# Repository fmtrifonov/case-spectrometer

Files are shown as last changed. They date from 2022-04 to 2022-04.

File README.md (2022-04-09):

# case-spectrometer
Корпус для монтирования сцинтилляционного гама-спектрометра основанного на ФЭУ-85 в короб. Обеспечивает плотный прижим кристалла к фотоэлектронному умножителю.

В данном репозитории находятся:
- описание 
- 3D модели для сцинтилляционного гама-спектрометра в форматах
  - программы Fusion360 ```.f3z```
  - универсальном формате САПР ```.step```
  - полигональном формате ```.stl``` для 3d печати.
- инструкция по сборке.

## описание

Сборка по сути представляет из себя фитинг, где в одной его части закреплен ФЭУ, а в другой кристалл сцинтиллятора. Обе эти части могут продольно перемещаться вдоль оси, но зафиксированы от вращения с помощью стоек, монтируемых в короб. Гайка при вращение перемещается по резьбе вокруг фэу и поджимает колпак с кристаллом, обеспечивая плотный контакт ФЭУ и сцинтиллятора.

## инструкция по сборке

Для печати нужно загрузить модели в формате ```.stl```. В директории ```\Images``` можно посмотреть оптимальную ориентацию моделей при использовании FDM печати.
В детали ```symetric side``` после печати нужно досверлить отверстия сверлом 3mm.

### порядок сборки
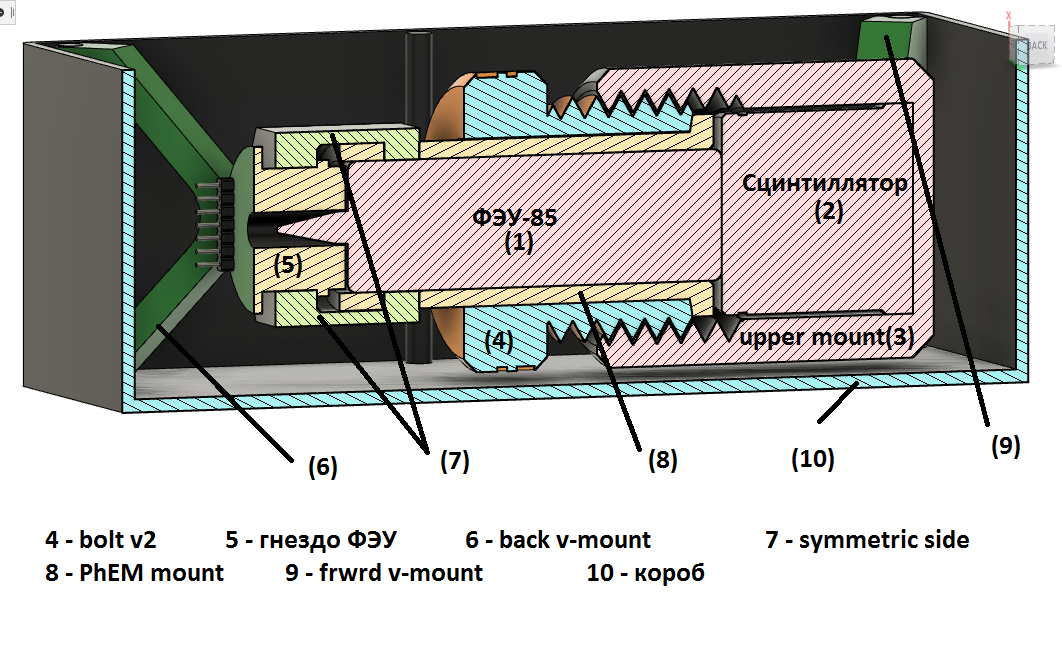
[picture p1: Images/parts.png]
Alt-текст Сборка в разрезе


На ФЭУ(1) установить деталь(8) и (4) как на рисунке.
Затем надевается гнездо питания(5) и деталь (8) фиксируется боковинками (7) снизу и сверху. 
В стакан (3) вставляется сцинтиллятор прозрачной стороной наружу. На него наносится оптическая смазка.
Стакан (3) навинчивается на болт (4) с запасом по ходу ~пол оборота. Прим. Запас хода оценивается расстоянием, которое пройдет кристалл до касания с ФЭУ, а не виднеющейся частью наружной резьбы.
К стакану прикручиваются ножки (9), а боковинки закрепляются ножками (6). Ножки (6) и (9) выравниваются в горизонталь (так, чтобы сборку можно было вставить в короб(10)), после чего гайка (4) закручевается до упора. 
ВНИМАНИЕ!!! Не переусердствуйте с затяжкой. В лучшем случае повредите печатные детали, в худшем - лопнет ФЭУ.

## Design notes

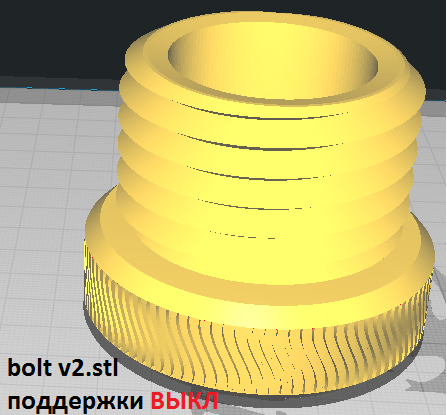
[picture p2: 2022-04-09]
Images/bolt v2.png

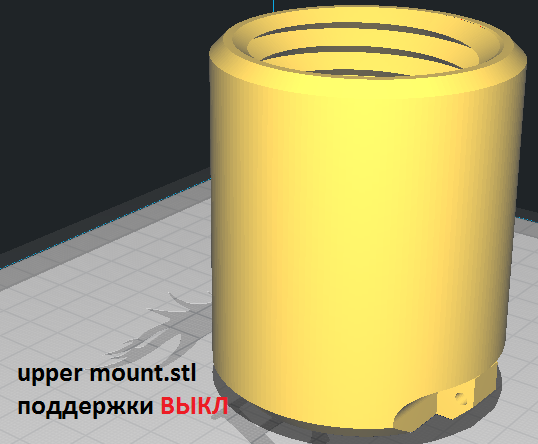
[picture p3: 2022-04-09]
Images/upper mount.png

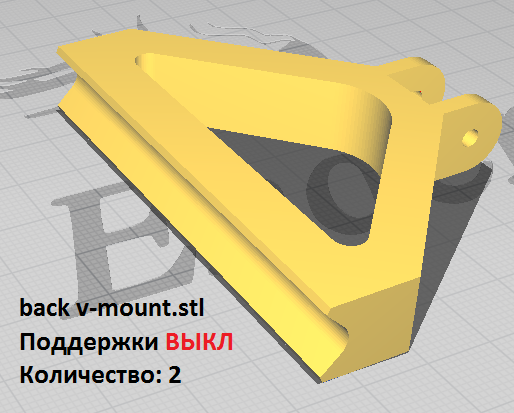
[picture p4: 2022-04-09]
Images/back v-mount.png

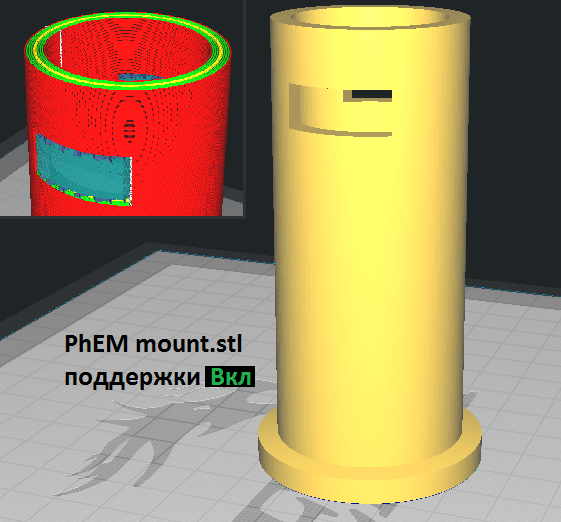
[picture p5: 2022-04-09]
Images/PhEM mount.png

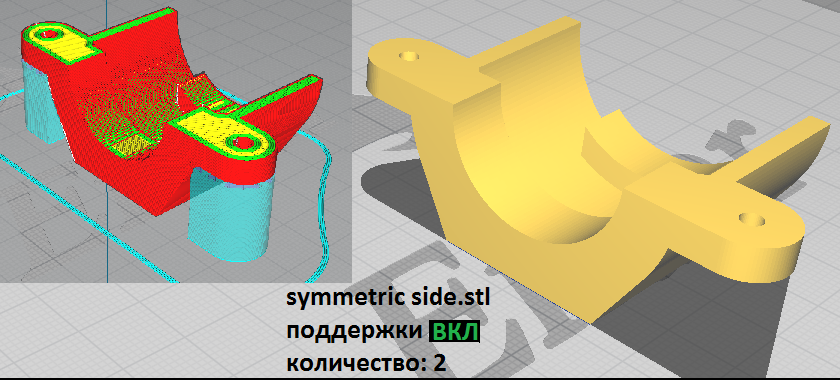
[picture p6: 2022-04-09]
Images/symmetric side.png

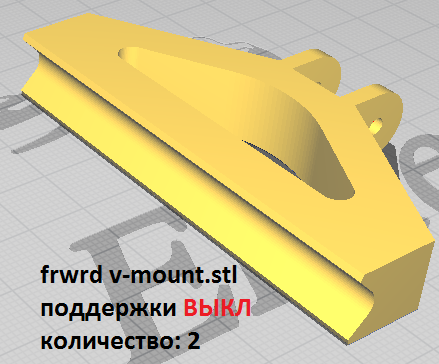
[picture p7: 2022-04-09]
Images/frwrd v-mount.png

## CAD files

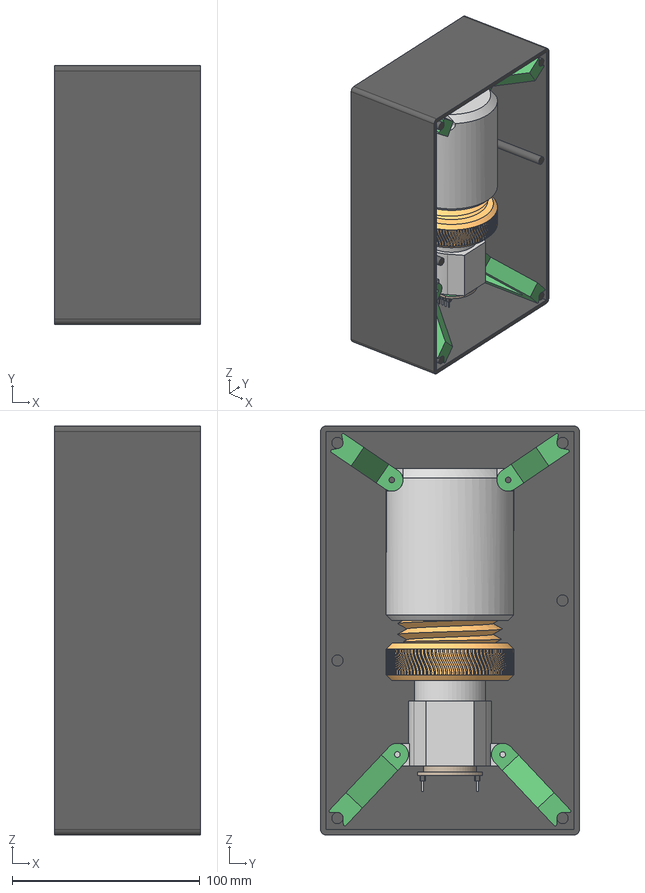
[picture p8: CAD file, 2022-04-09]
step/сцинтилляционный спектрометр гамма-излучения v53.step
78.0 x 138.0 x 218.0 mm
ФЭУ - 85
сцинтиллятор
гнездо
коробка
верхнее крепление
крепеж ФЭУ
задняя стойка
винт
симметричная боковина x 2
задняя стойка_ 1
передняя стойка x 2

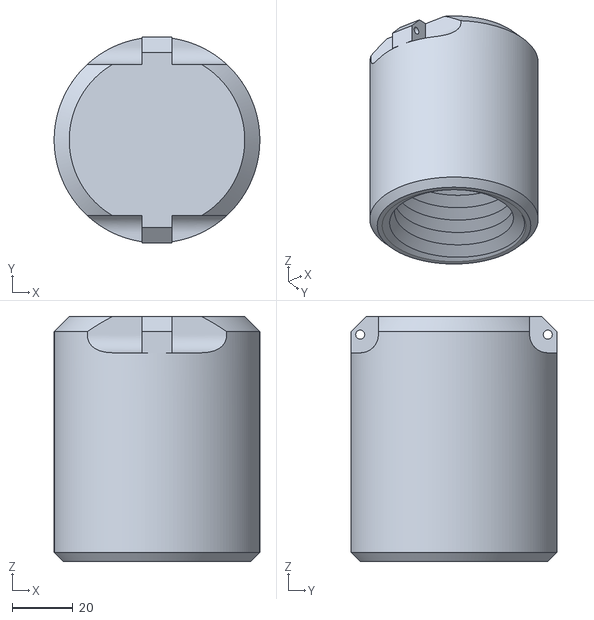
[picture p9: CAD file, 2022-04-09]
stl/upper mount.stl
68.0 x 68.0 x 81.0

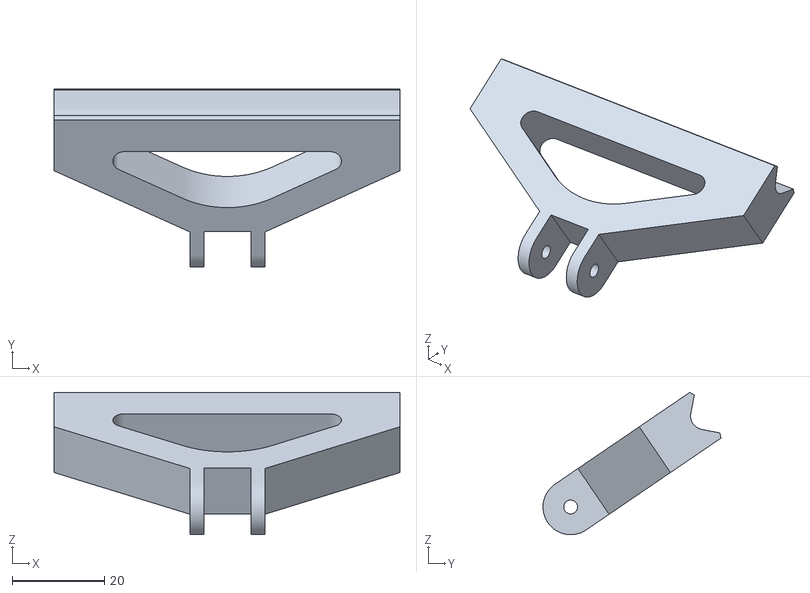
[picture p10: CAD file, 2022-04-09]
stl/frwrd v-mount.stl
75.0 x 38.6 x 30.9

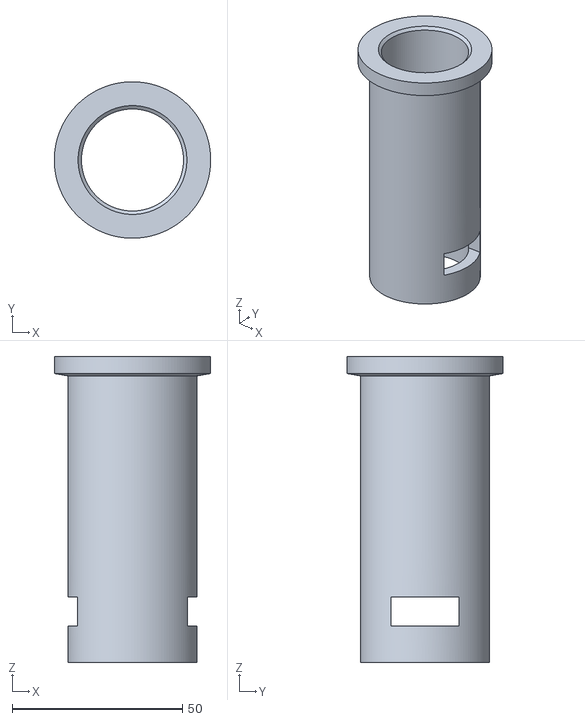
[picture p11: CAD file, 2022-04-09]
stl/PhEM mount.stl
46.0 x 46.0 x 90.0

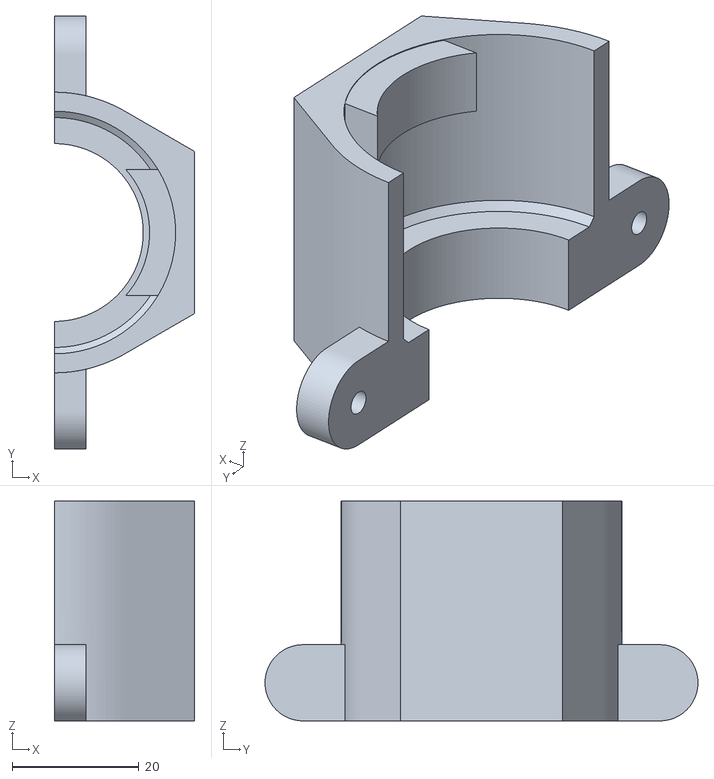
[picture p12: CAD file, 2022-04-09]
stl/symmetric side.stl
22.1 x 68.2 x 34.6

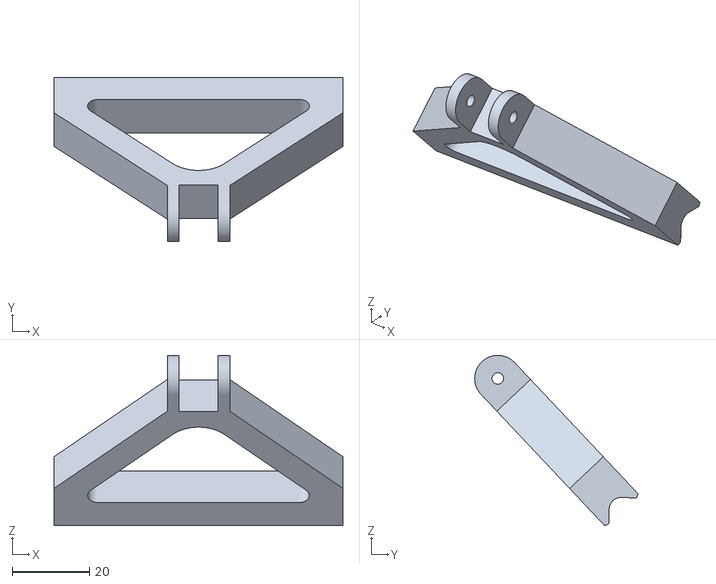
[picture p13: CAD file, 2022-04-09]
stl/back v-mount.stl
75.0 x 42.4 x 44.2

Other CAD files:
f3d/сцинтилляционный спектрометр гамма-излучения v53.f3z

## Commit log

2022-04-09 Добавлены изображения, step и stl
    [PhEM mount.stl, back v-mount.stl, frwrd v-mount.stl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]
2022-04-09 +фотка
2022-04-09 название
2022-04-09 Добавлен файл fusion360. ЗАЧЕМ?
    [сцинтилляционный спектрометр гамма-излучения v53.f3z]
